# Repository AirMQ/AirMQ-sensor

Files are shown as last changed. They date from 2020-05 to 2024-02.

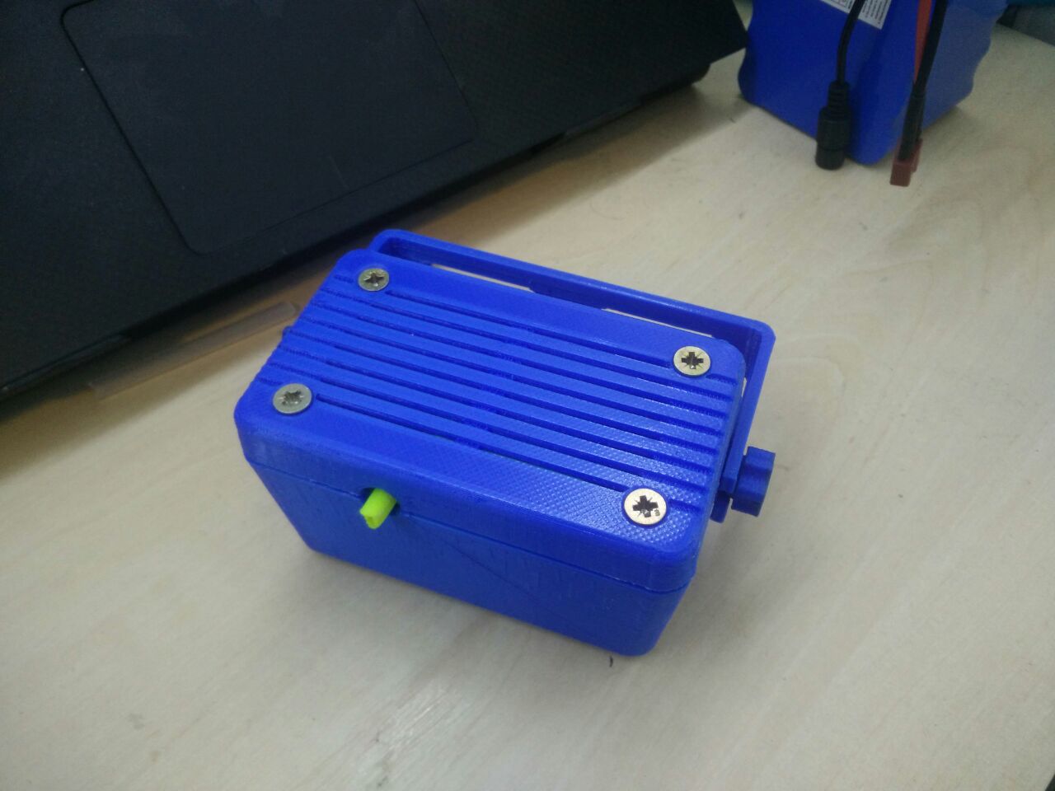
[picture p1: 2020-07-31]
Hardware/Case for 3D print/Case top view.jpg

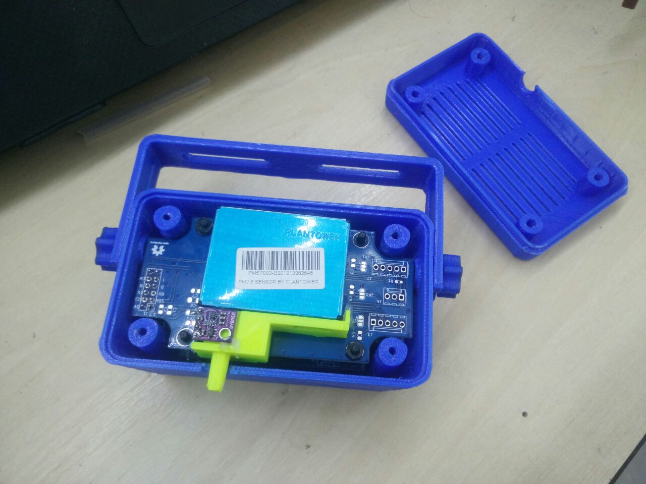
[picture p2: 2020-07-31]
Hardware/Case for 3D print/Open case view.jpg

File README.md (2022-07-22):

# AirMQ-sensor
Root repository for AirMQ hardware project

AirMQ toolkit consists of main MCU and several sensor boards designed with common form factor in mind. Currently, particulate matter, radiation and electrochemical sensor boards are available. 

MCU board includes advanced power circuitry which makes possible the use of reduced consumption modes while powering from batteries or solar panels. All ESP8266’s gpio pins are accessible with a separate 16-pin connector sharing pin numbering with most popular development boards. 

All boards share the same type of extension connector which allows for stackability limited by sensors size.

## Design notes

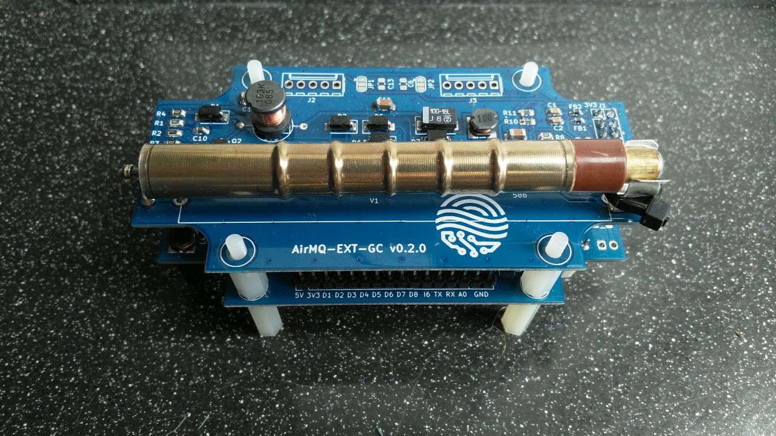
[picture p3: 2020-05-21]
Images/GC-2-Down.jpg

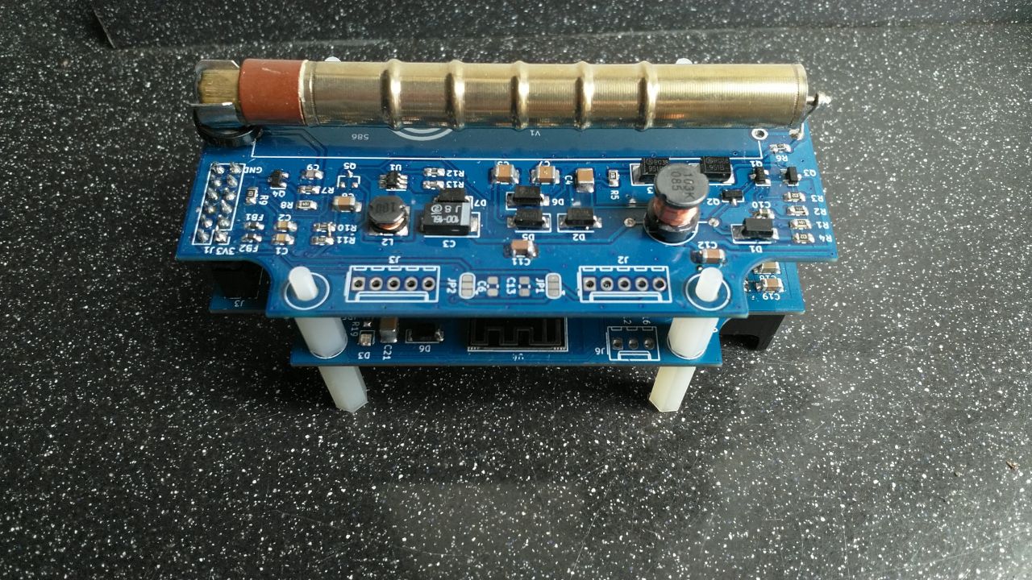
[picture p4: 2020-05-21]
Images/GC-2-Up.jpg

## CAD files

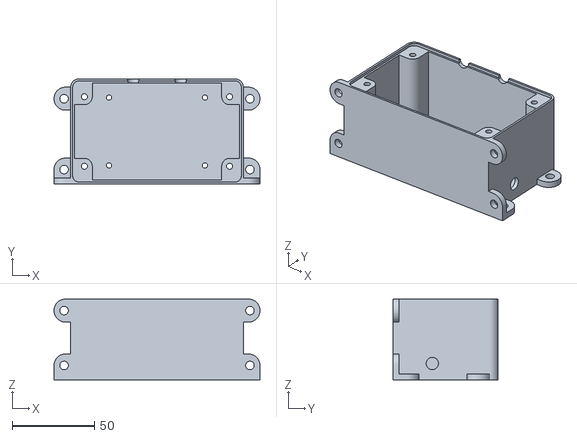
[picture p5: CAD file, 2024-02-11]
Hardware/Case for 3D print/v2/Main body.stl
125.0 x 63.8 x 49.1

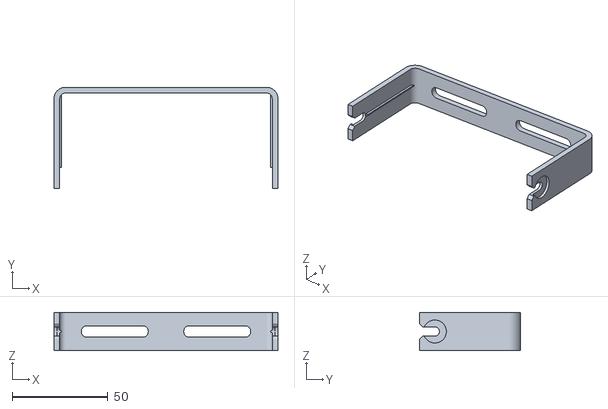
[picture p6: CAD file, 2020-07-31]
Hardware/Case for 3D print/Bracket.STL
117.0 x 53.0 x 20.0

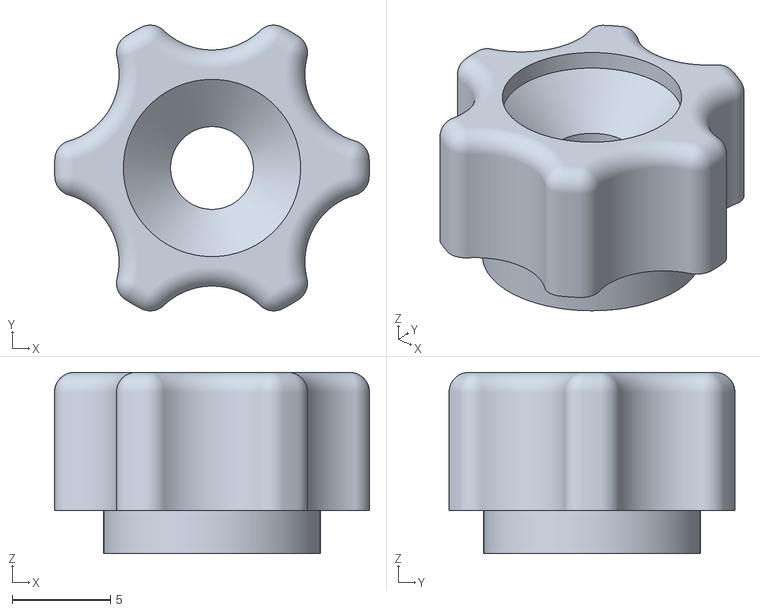
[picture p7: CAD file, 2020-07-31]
Hardware/Case for 3D print/M4 Knob.STL
16.0 x 14.5 x 9.20

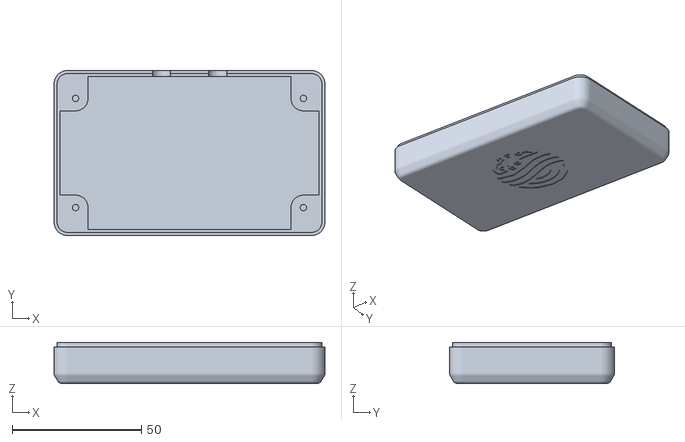
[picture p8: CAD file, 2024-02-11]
Hardware/Case for 3D print/v2/Lid.stl
104.8 x 63.8 x 15.9

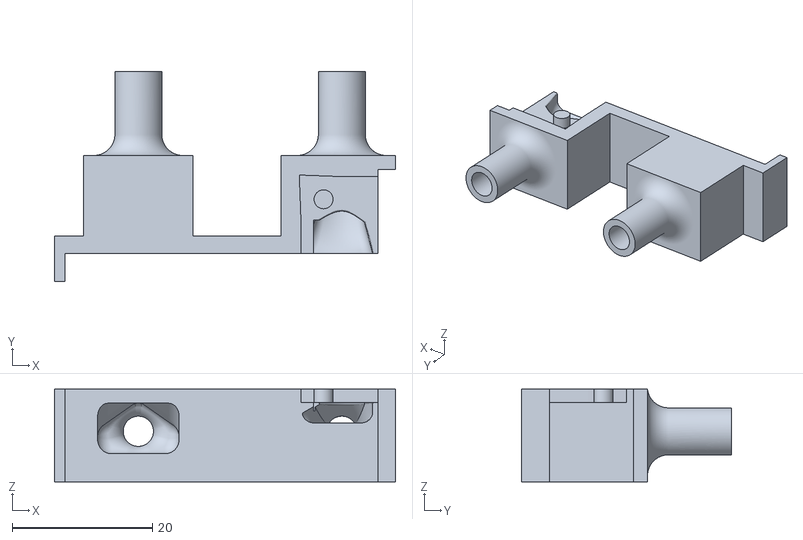
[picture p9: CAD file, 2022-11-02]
Hardware/Case for 3D print/v2/Duct mk3.STL
48.6 x 30.0 x 13.2

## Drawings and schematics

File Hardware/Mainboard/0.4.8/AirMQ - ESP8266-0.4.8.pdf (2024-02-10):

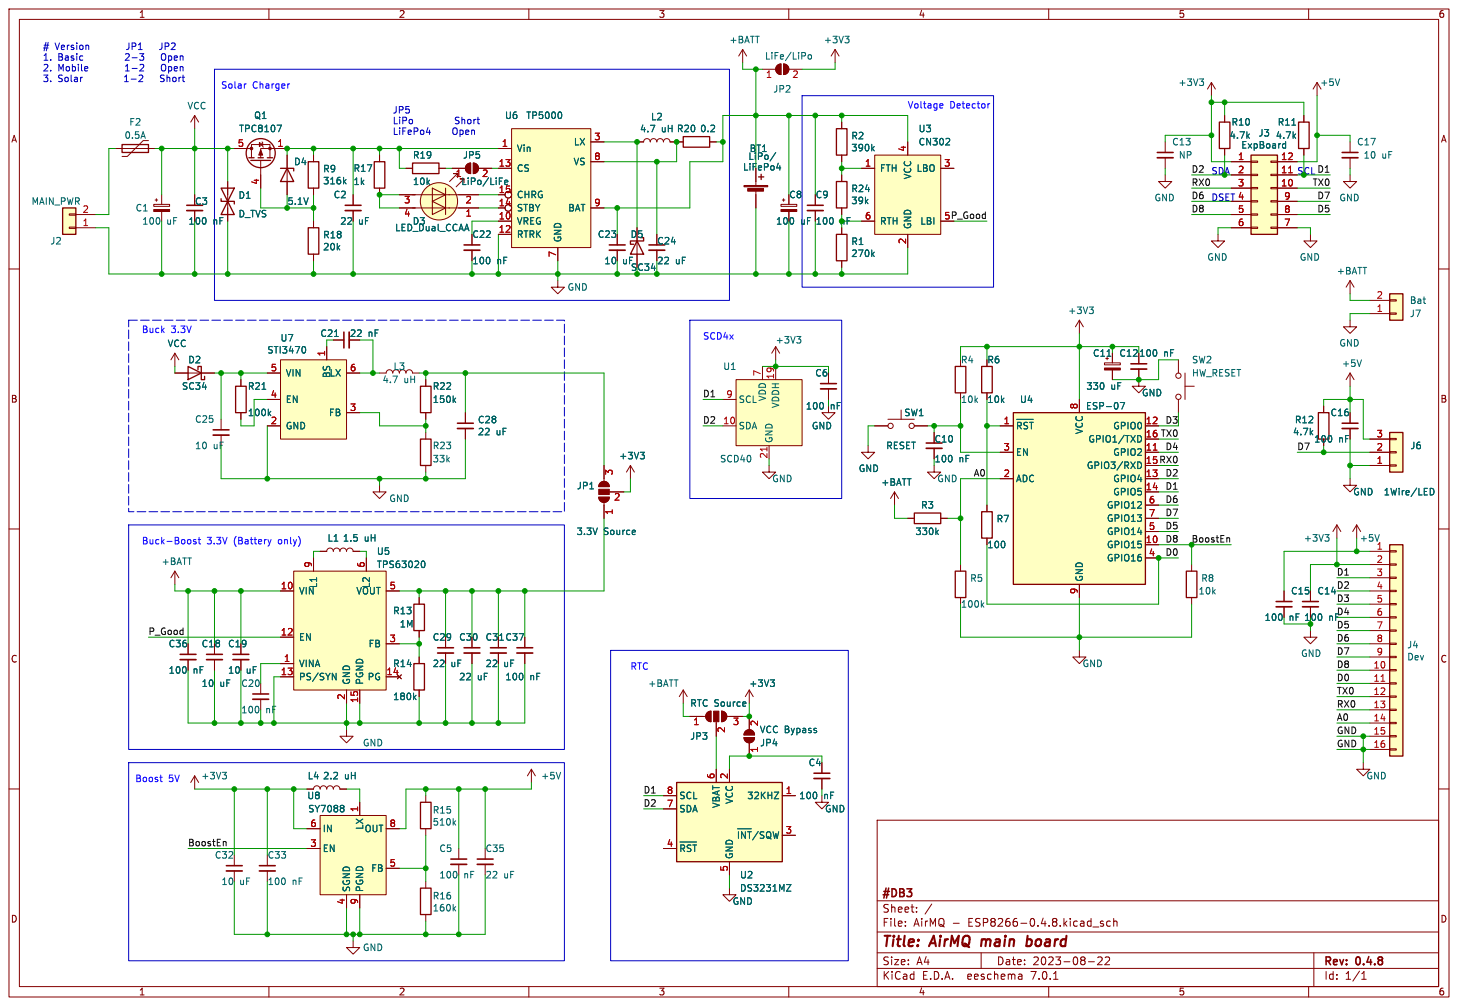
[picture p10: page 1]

1 GND 2 FB 3 EN 4 VIN 5

Id: 1/1 Title: AirMQ main board

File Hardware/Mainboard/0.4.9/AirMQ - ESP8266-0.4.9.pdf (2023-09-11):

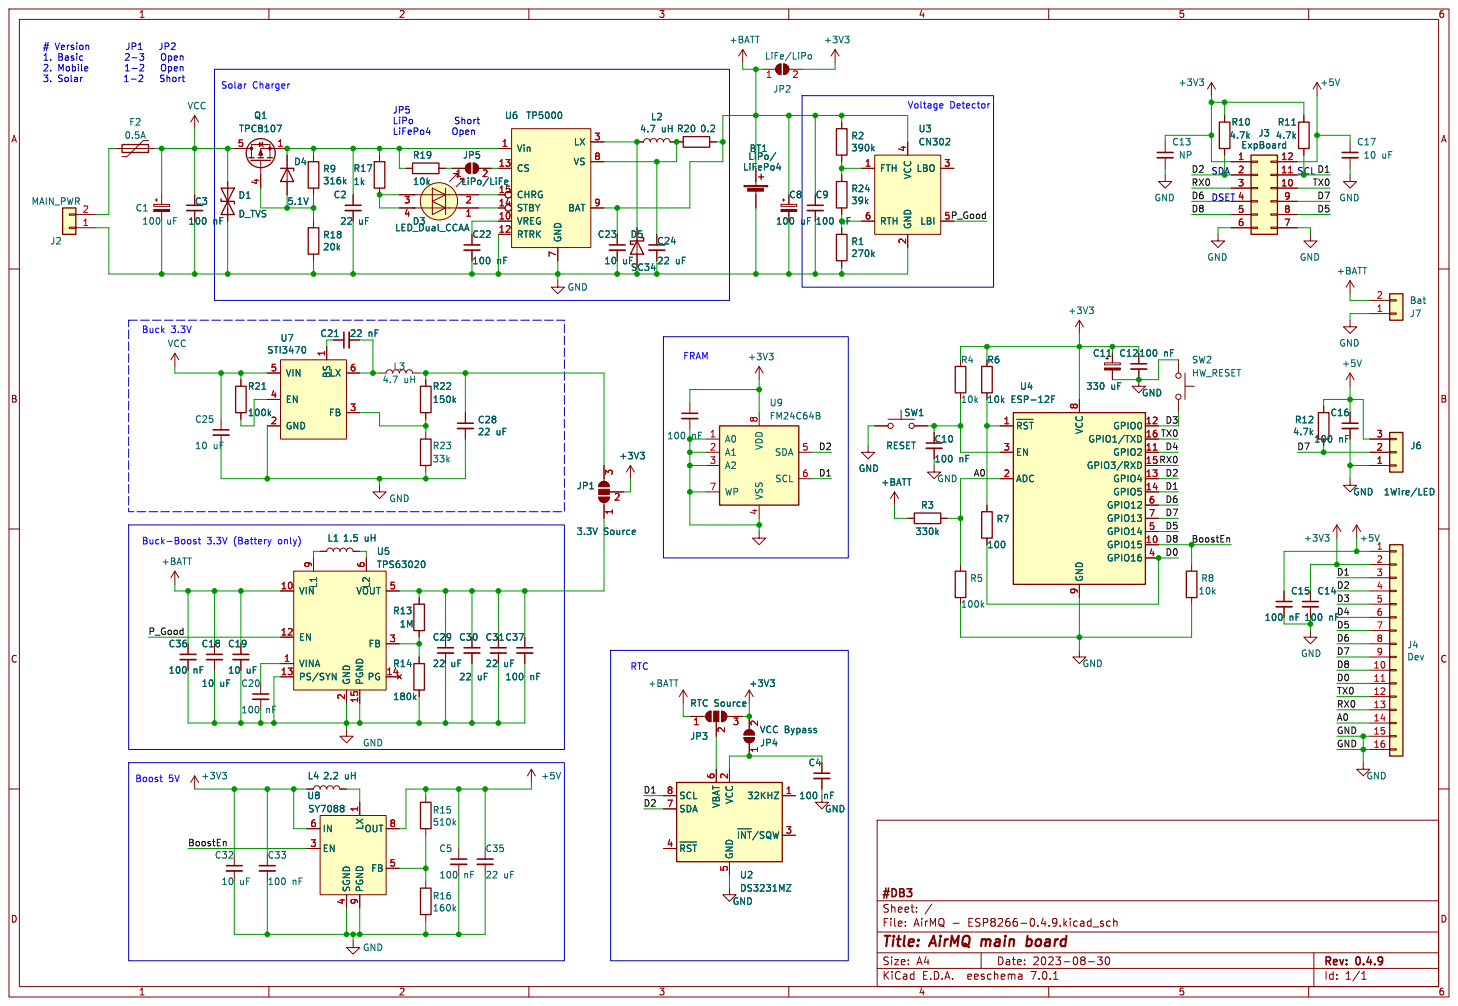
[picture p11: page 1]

1 GND 2 FB 3 EN 4 VIN 5

4 SDA 5 SCL 6 WP 7 VDD

Id: 1/1 Title: AirMQ main board

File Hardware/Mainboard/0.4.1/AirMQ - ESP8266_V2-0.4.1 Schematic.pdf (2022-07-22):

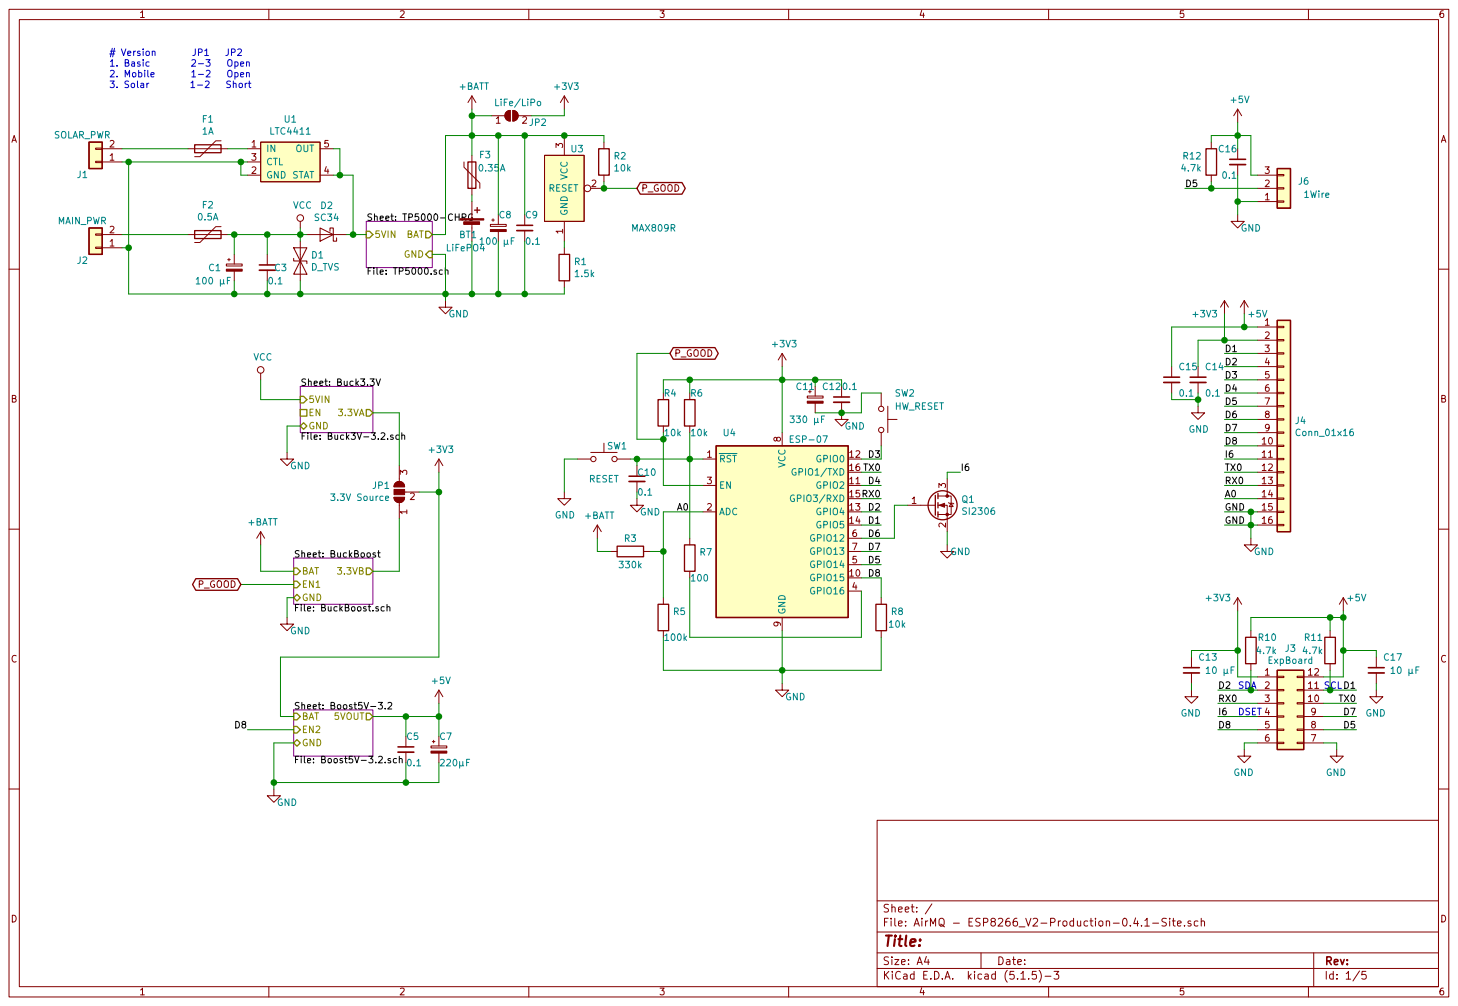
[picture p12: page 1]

Sheet: BuckBoost File: BuckBoost.sch BAT EN1 GND

File: AirMQ - ESP8266_V2-Production-0.4.1-Site.sch Sheet: / Sheet: Boost5V-3.2 File: Boost5V-3.2.sch BAT GND
5VOUT EN2

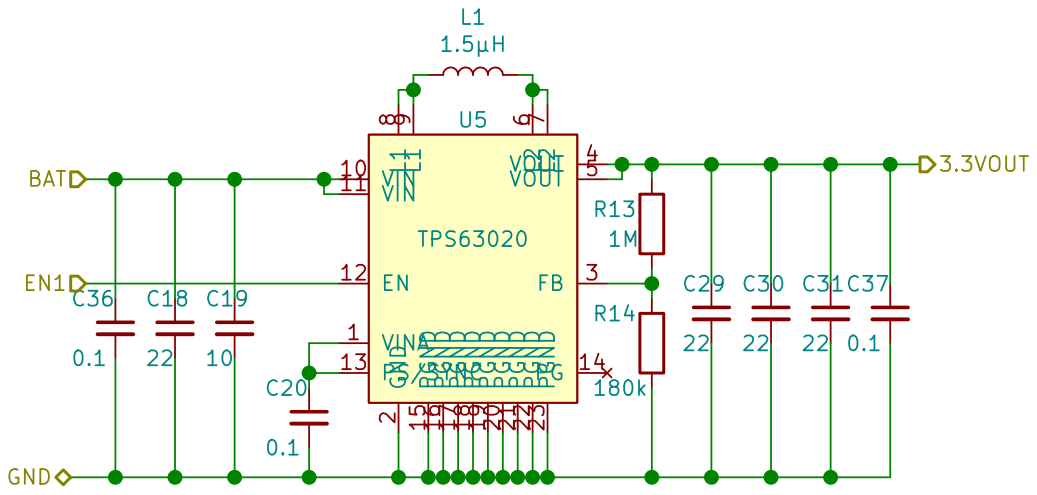
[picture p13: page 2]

2 PGND 20 PGND 21 PGND 22 PGND 23 FB 3 VOUT 4 L2 5

Id: 2/5 Title: File: BuckBoost.sch Sheet: /BuckBoost/

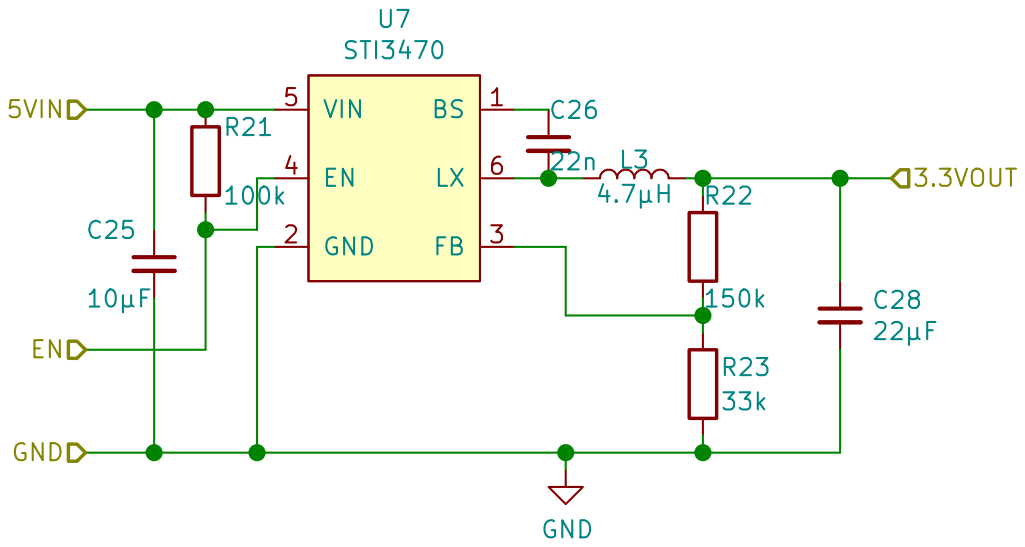
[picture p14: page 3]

Id: 3/5 Title: File: Buck3V-3.2.sch Sheet: /Buck3.3V/

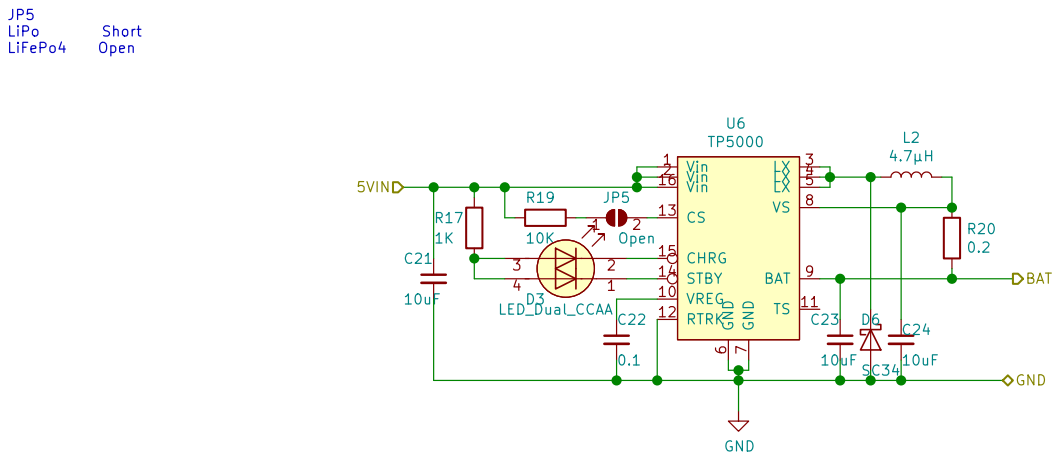
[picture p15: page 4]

Id: 4/5 Title: File: TP5000.sch Sheet: /TP5000-CHRG/

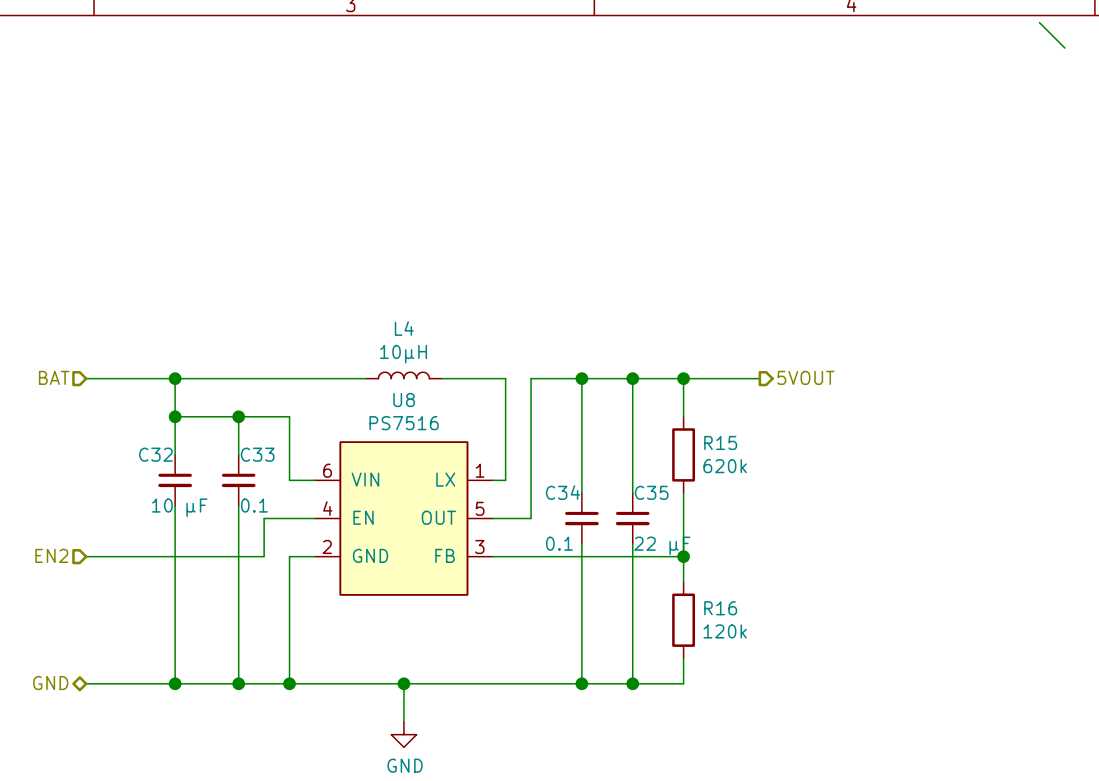
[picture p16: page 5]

Id: 5/5 Title: File: Boost5V-3.2.sch Sheet: /Boost5V-3.2/

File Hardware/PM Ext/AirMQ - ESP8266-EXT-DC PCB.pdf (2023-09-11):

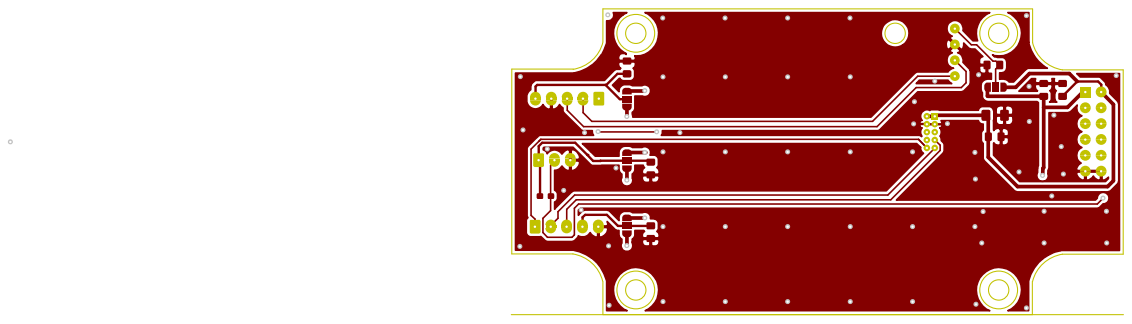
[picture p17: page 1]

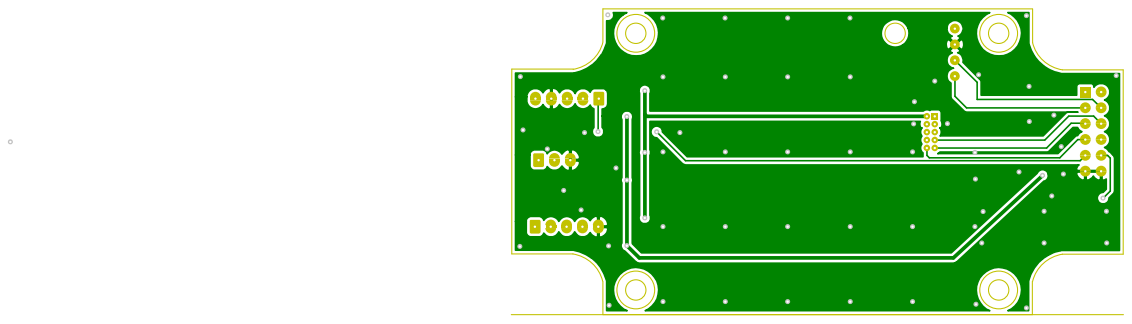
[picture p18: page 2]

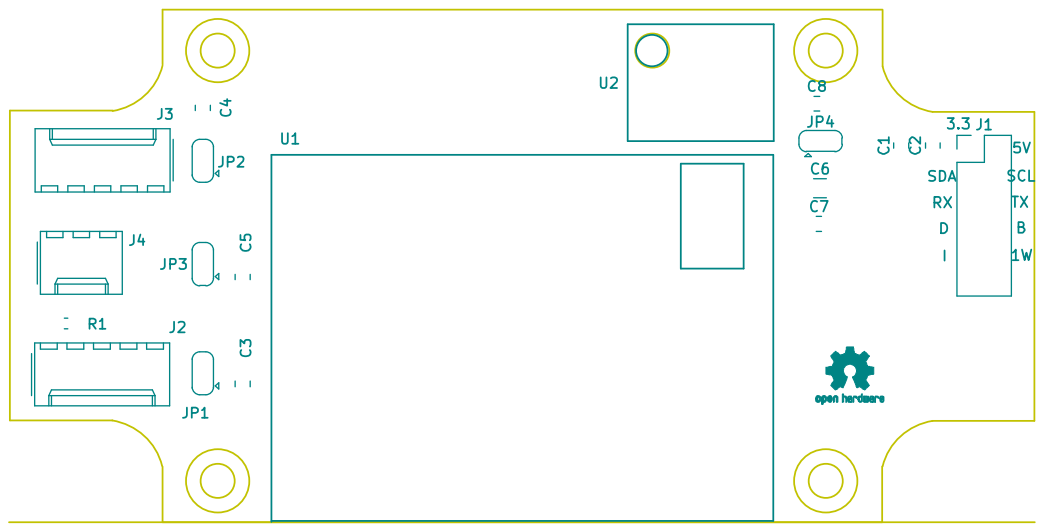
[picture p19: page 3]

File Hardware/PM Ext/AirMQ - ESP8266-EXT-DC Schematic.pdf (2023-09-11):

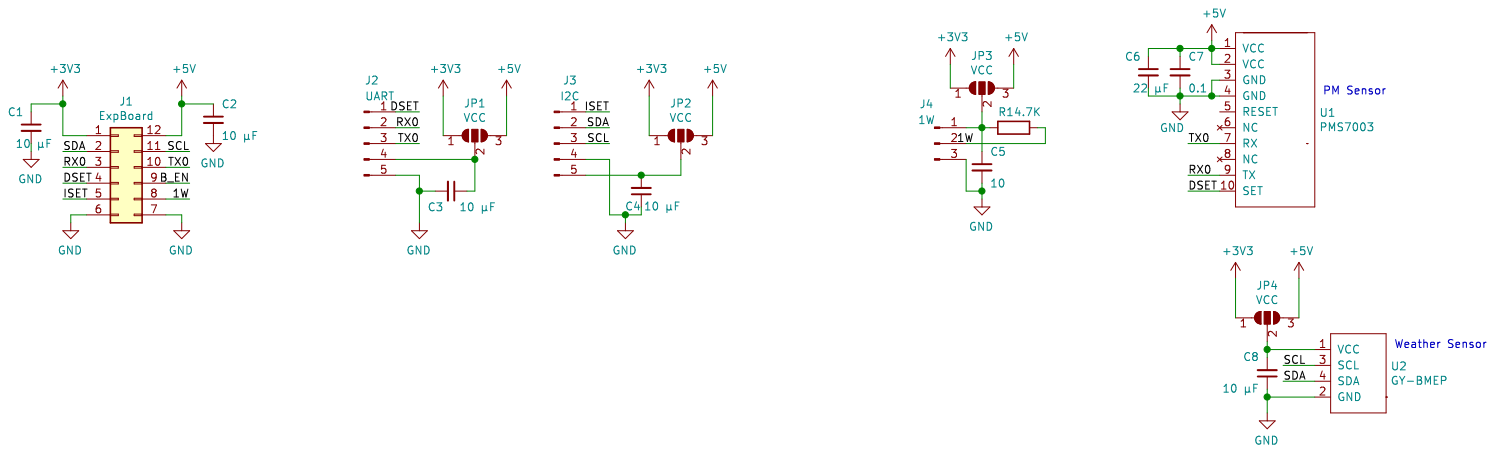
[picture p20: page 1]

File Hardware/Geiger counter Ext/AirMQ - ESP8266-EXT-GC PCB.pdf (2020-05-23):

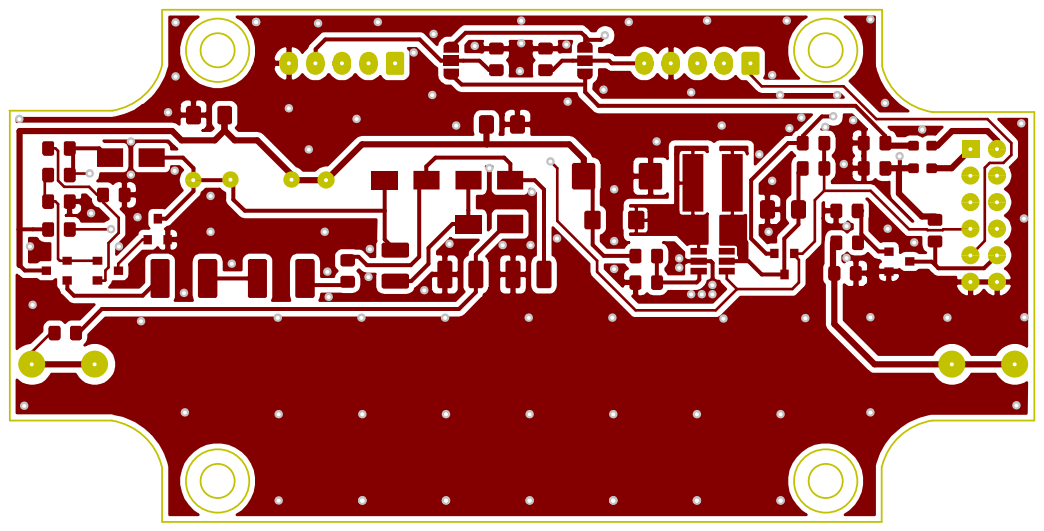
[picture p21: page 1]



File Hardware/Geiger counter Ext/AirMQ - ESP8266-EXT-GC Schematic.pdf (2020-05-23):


File: AirMQ - ESP8266-EXT-GC-13.sch Sheet: / R5




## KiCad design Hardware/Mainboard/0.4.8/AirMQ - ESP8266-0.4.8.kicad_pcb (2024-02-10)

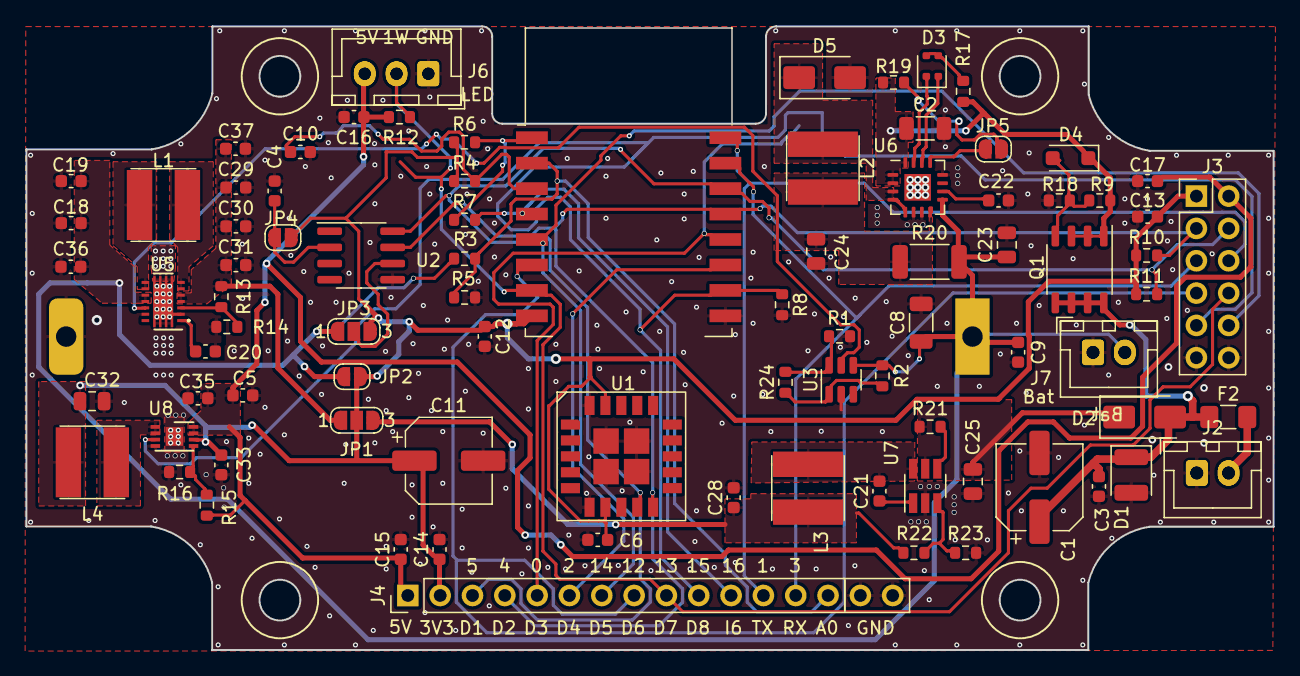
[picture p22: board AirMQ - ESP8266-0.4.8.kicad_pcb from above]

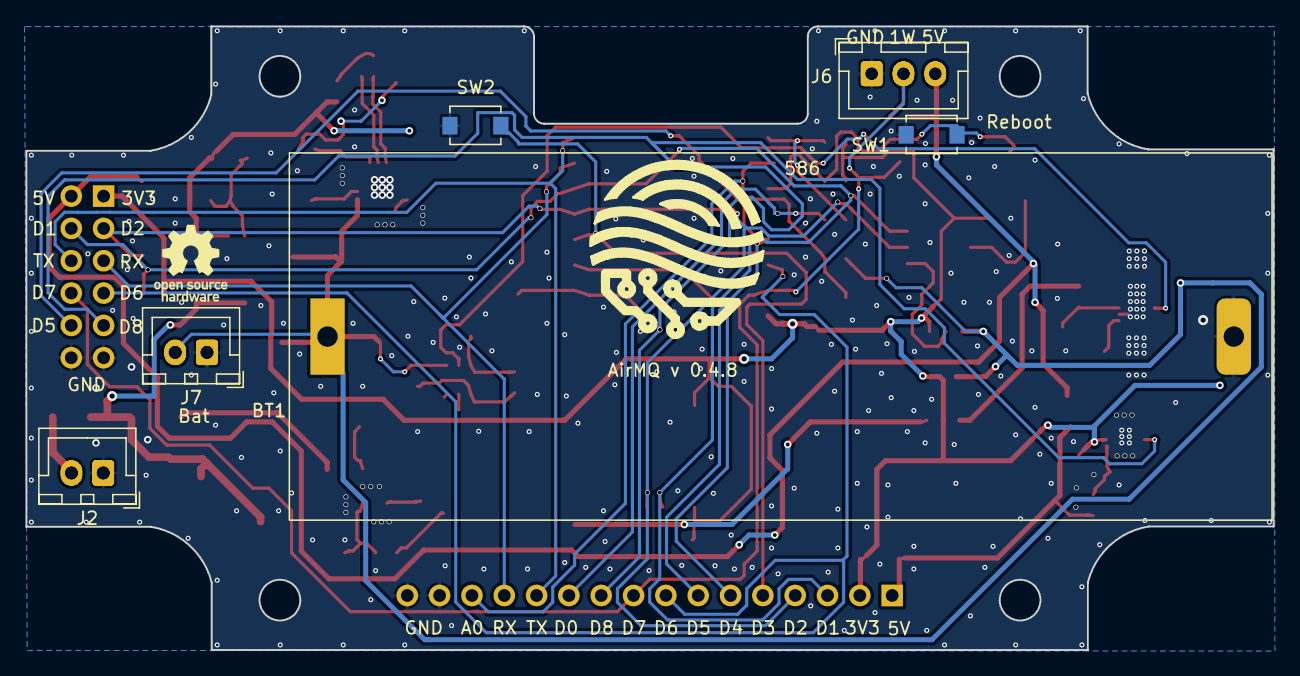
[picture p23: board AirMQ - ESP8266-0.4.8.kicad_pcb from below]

Board: 2 copper layers, 98.0 x 49.0 mm, 93 parts (7 on the bottom side), 48 nets.

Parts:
586: AirMQ_Logo; AirMQ_Logo_new
BT1: LiPo/ LiFePo4; 26650
C1: 100 uF; CP_Elec_6.3x7.7
C2: 22 uF; C_1206_3216Metric
C3, C4, C5, C6, C9, C10, C12, C14, C15, C16, C20, C22, C33, C36, C37: 100 nF; C_0603_1608Metric
C8: 100 uF; C_1206_3216Metric
C11: 330 uF; CP_Elec_6.3x7.7
C13: NP; C_0603_1608Metric
C17, C18, C19: 10 uF; C_0603_1608Metric
C21: 22 nF; C_0603_1608Metric
C23, C25, C32: 10 uF; C_0805_2012Metric
C24: 22 uF; C_0805_2012Metric
C28, C29, C30, C31, C35: 22 uF; C_0603_1608Metric
D1: D_TVS; D_1210_3225Metric
D2, D5: SC34; D_SMA
D3: LED_Dual_CCAA; LED_0603_Dual
D4: 5.1V; D_SOD-123F
F2: 0.5A; Fuse_1206_3216Metric_Pad1.42x1.75mm_HandSolder
J2, J2#2: MAIN_PWR; JST_XH_B2B-XH-A_1x02_P2.50mm_Vertical
J3: ExpBoard; PinHeader_2x06_P2.54mm_Vertical_CC
J4: Dev; PinHeader_1x16_P2.54mm_Vertical
J6, J6#2: 1Wire/LED; JST_XH_B3B-XH-A_1x03_P2.50mm_Vertical
J7, J7#2: Bat; JST_XH_B2B-XH-A_1x02_P2.50mm_Vertical
JP1: 3.3V Source; SolderJumper-3_P1.3mm_Open_RoundedPad1.0x1.5mm_NumberLabels
JP2: LiFe/LiPo; SolderJumper-2_P1.3mm_Open_RoundedPad1.0x1.5mm
JP3: RTC Source; SolderJumper-3_P1.3mm_Open_RoundedPad1.0x1.5mm_NumberLabels
JP4: VCC Bypass; SolderJumper-2_P1.3mm_Open_RoundedPad1.0x1.5mm
JP5: LiPo/LiFe; SolderJumper-2_P1.3mm_Open_RoundedPad1.0x1.5mm
L1: 1.5 uH; Inductor_CD53
L2, L3: 4.7 uH; Inductor_CD53
L4: 2.2 uH; Inductor_CD53
Q1: TPC8107; SOP-8_3.9x4.9mm_P1.27mm
R1: 270k; R_0603_1608Metric
R2: 390k; R_0603_1608Metric
R3: 330k; R_0603_1608Metric
R4, R6, R8, R19: 10k; R_0603_1608Metric
R5, R21: 100k; R_0603_1608Metric
R7: 100; R_0603_1608Metric
R9: 316k; R_0603_1608Metric
R10, R11, R12: 4.7k; R_0603_1608Metric
R13: 1M; R_0603_1608Metric
R14: 180k; R_0603_1608Metric
R15: 510k; R_0603_1608Metric
R16: 160k; R_0603_1608Metric
R17: 1k; R_0603_1608Metric
R18: 20k; R_0603_1608Metric
R20: 0.2; R_2010_5025Metric
R22: 150k; R_0603_1608Metric
R23: 33k; R_0603_1608Metric
R24: 39k; R_0603_1608Metric
SW1: RESET; SW_PUSH_4x3x2
SW2: HW_RESET; SW_PUSH_4x3x2
U1: SCD40
U2: DS3231MZ; SOIC-8_3.9x4.9mm_P1.27mm
U3: CN302; SOT-23-6
U4: ESP-07; ESP-12E_noSPI
U5: TPS63020; QFN14-3X4MM
U6: TP5000; QFN-16-1EP_4x4mm_P0.65mm_EP2.1x2.1mm
U7: STI3470; SOT-23-6_Handsoldering
U8: SY7088; DFN-8-1EP_3x2mm_P0.5mm_EP1.36x1.46mm

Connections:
+3V3: C6.1, C11.1, C12.1, C13.1, C14.1, C32.1, C33.1, J3.1, J4.2, JP1.2 (C), JP2.2 (B), JP3.3 (B), JP4.2 (B), L4.1, R4.1, R6.1, R10.1, R11.1, U1.7 (VDD), U1.19 (VDDH), U4.8 (VCC), U8.6 (IN)
+5V: C5.1, C15.1, C16.1, C17.1, C35.1, J3.12, J4.1, J6.3, J6#2.3, R12.1, R15.1, U8.7 (OUT), U8.8 (OUT)
+BATT: BT1.1 (+), C8.1, C9.1, C18.1, C19.1, C23.1, C36.1, J7.2, J7#2.2, JP2.1 (A), JP3.1 (A), R2.1, R3.2, R20.2, U3.4 (VCC), U5.10 (VIN), U5.11 (VIN), U6.9 (BAT)
/A0: J4.14, R3.1, R5.1, U4.2 (ADC)
/BoostEn: J3.5, J4.10, R8.1, U4.10 (GPIO15), U8.3 (EN)
/D0: J4.11, R7.2, U4.4 (GPIO16)
/D1: J3.11, J4.3, R11.2, U1.9 (SCL), U2.8 (SCL), U4.14 (GPIO5)
/D2: J3.2, J4.4, R10.2, U1.10 (SDA), U2.7 (SDA), U4.13 (GPIO4)
/D3: J4.5, SW2.2, U4.12 (GPIO0)
/D4: J4.6, U4.11 (GPIO2)
/D5: J3.8, J4.7, U4.5 (GPIO14)
/D6: J3.4, J4.8, U4.6 (GPIO12)
/D7: J3.9, J4.9, J6.2, J6#2.2, R12.2, U4.7 (GPIO13)
/P_Good: U3.5 (LBI), U5.12 (EN)
/RX0: J3.3, J4.13, U4.15 (GPIO3/RXD)
/TX0: J3.10, J4.12, U4.16 (GPIO1/TXD)
GND: BT1.2 (-), C1.2, C2.2, C3.2, C4.2, C5.2, C6.2, C8.2, C9.2, C10.2, C11.2, C12.2, C13.2, C14.2, C15.2, C16.2, C17.2, C18.2, C19.2, C20.2, C22.2, C23.2, C24.2, C25.2, C28.2, C29.2, C30.2, C31.2, C32.2, C33.2, C35.2, C36.2, C37.2, D1.2 (A2), D5.2 (A), J2.1, J2#2.1, J3.6, J3.7, J4.15, J4.16, J6.1, J6#2.1, J7.1, J7#2.1, R1.2, R5.2, R8.2, R14.2, R16.2, R18.2, R23.2, SW1.1, SW2.1, U1.6 (GND), U1.20 (GND), U1.21 (GND), U2.5 (GND), U3.2 (GND), U4.9 (GND), U5.2 (GND), U5.13 (PS/SYN), U5.15 (PGND), U5.16 (PGND), U5.17 (PGND), U5.18 (PGND), U5.19 (PGND), U5.20 (PGND), U5.21 (PGND), U5.22 (PGND), U5.23 (PGND), U6.6 (GND), U6.7 (GND), U6.12 (RTRK), U6.17 (GND), U7.2 (GND), U8.4 (SGND), U8.9 (PGND)
unnamed: C25.1, D2.1 (K), R21.1, U7.5 (VIN)
unnamed: D3.3 (A1), D3.4 (A2), R17.2
unnamed: D3.2 (K1), U6.15 (CHRG)
unnamed: D3.1 (K2), U6.14 (STBY)
unnamed: D4.2 (A), Q1.4 (G), R9.2, R18.1
unnamed: C2.1, D4.1 (K), Q1.1 (S), Q1.2 (S), Q1.3 (S), R9.1, R17.1, R19.2, U6.1 (Vin), U6.2 (Vin), U6.16 (Vin)
unnamed: D5.1 (K), L2.1, U6.3 (LX), U6.4 (LX), U6.5 (LX)
unnamed: F2.2, J2.2, J2#2.2
unnamed: C29.1, C30.1, C31.1, C37.1, JP1.1 (A), R13.1, U5.4 (VOUT), U5.5 (VOUT)
unnamed: C28.1, JP1.3 (B), L3.2, R22.1
unnamed: JP3.2 (C), U2.6 (VBAT)
unnamed: C4.1, JP4.1 (A), U2.2 (VCC)
unnamed: JP5.1 (A), R19.1
unnamed: JP5.2 (B), U6.13 (CS)
unnamed: L1.1, U5.8 (L1), U5.9 (L1)
unnamed: L1.2, U5.6 (L2), U5.7 (L2)
unnamed: L4.2, U8.1 (LX), U8.2 (LX)
unnamed: R2.2, R24.1, U3.1 (FTH)
unnamed: R1.1, R24.2, U3.6 (RTH)
unnamed: C10.1, R4.2, SW1.2, U4.3 (EN)
unnamed: R6.2, R7.1, U4.1 (~RST)
unnamed: R13.2, R14.1, U5.3 (FB)
unnamed: C20.1, U5.1 (VINA)
unnamed: C22.1, U6.10 (VREG)
unnamed: C24.1, L2.2, R20.1, U6.8 (VS)
unnamed: C21.1, U7.1 (BS)
unnamed: R21.2, U7.4 (EN)
unnamed: R22.2, R23.1, U7.3 (FB)
unnamed: C21.2, L3.1, U7.6 (LX)
unnamed: R15.2, R16.1, U8.5 (FB)
VCC: C1.1, C3.1, D1.1 (A1), D2.2 (A), F2.1, Q1.5 (D), Q1.6 (D), Q1.7 (D), Q1.8 (D)

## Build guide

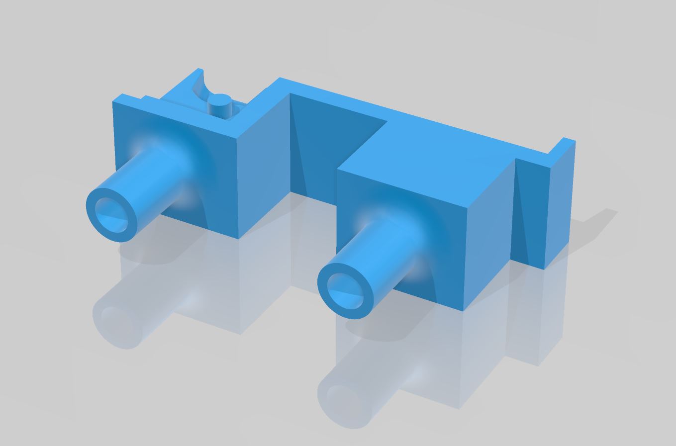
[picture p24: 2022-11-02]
Hardware/Case for 3D print/duct_mk3.JPG

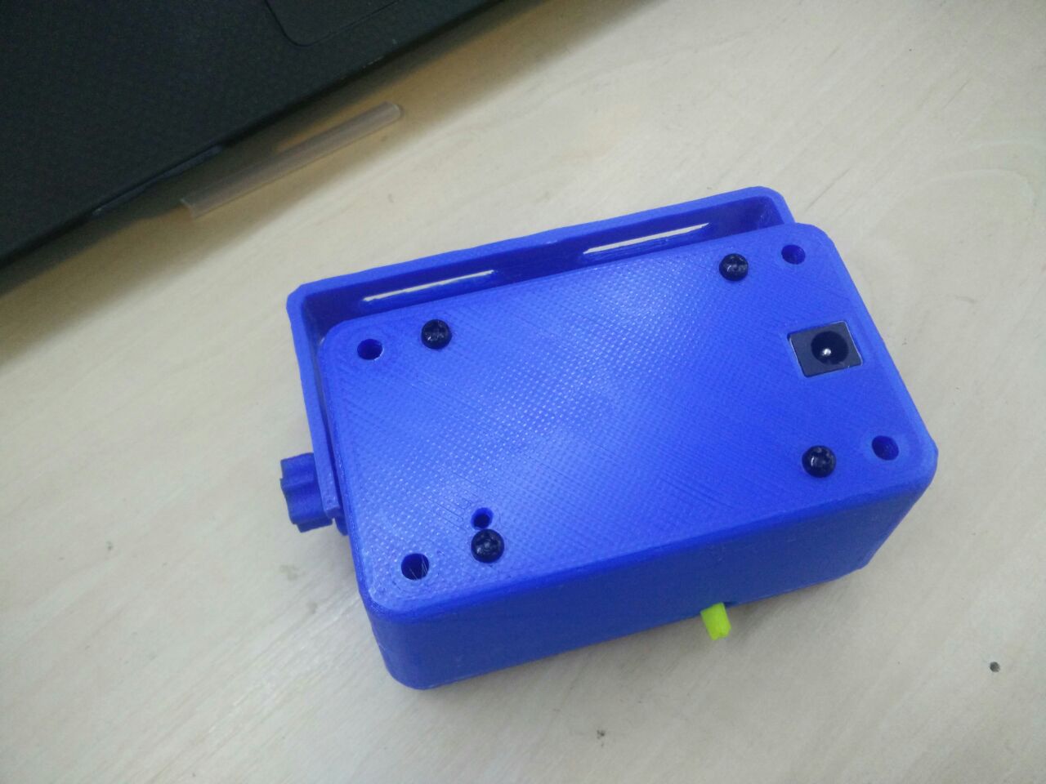
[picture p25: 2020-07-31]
Hardware/Case for 3D print/Case bottom view.jpg

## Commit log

2020-05-23 Create Schematic
2020-05-28 added boards description
2020-07-31 Add files via upload
    Main case part
2022-11-02 2-way air duct for PMS7003
    [Duct mk3.STL]
2024-02-10 added .sch file
    [AirMQ - ESP8266-0.4.9.kicad_sch]
2024-02-10 added .pcb file
    [AirMQ - ESP8266-0.4.9.kicad_pcb]
2024-02-10 added 0.4.8 pcb
    [AirMQ - ESP8266-0.4.8.kicad_pcb, AirMQ - ESP8266-0.4.8.kicad_sch]
2024-02-10 added pdf schematics
2024-02-11 added v2 housing
    [Lid.stl, Main body.stl]
2024-10-07 version 20241007 for ESP32-S3, OTA upgrade
2024-10-07 version 20241007 for ESP32-S3, for initial upload
2026-01-27 Added README.md and stl file
2026-01-27 added schematic pdf
2026-01-27 added weather sensor module
